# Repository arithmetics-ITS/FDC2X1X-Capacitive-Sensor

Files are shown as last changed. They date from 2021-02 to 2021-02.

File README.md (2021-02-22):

# Breakout Board: FDC2212 EMI-Resistant 28-Bit Capacitance-to-Digital Converter for Proximity and  Level Sensing Application
## Description

Capacitive sensing is a low-power, low-cost, high-resolution contactless sensing technique that can be applied to a variety of applications ranging from proximity detection and gesture recognition to remote liquid level sensing. The sensor in a capacitive sensing system is any metal or conductor, allowing for low cost and highly flexible system design. The main challenge limiting sensitivity in capacitive sensing applications is noise susceptibility of the sensors. With the FDC2x1x innovative EMI resistant
architecture, performance can be maintained even in presence of high-noise environments.

The FDC2x1x is a multi-channel family of noise-and EMI-resistant, high-resolution, high-speed capacitance-to-digital converters for  implementing capacitive sensing solutions. The devices employ an innovative narrow-band based architecture to offer high rejection of noise and interferers while providing high resolution at highspeed. The devices support a wide excitation frequency range, offering flexibility in system design. A wide frequency range is especially useful for reliable sensing of conductive liquids such as detergent, soap, and ink.

## Features

- Texas Instruments FDC2212
- CTS Model 625 - 40MHz ultra-low voltage clock oscillator
-  SiP3243 - Ultra Low Leakage Load Switch

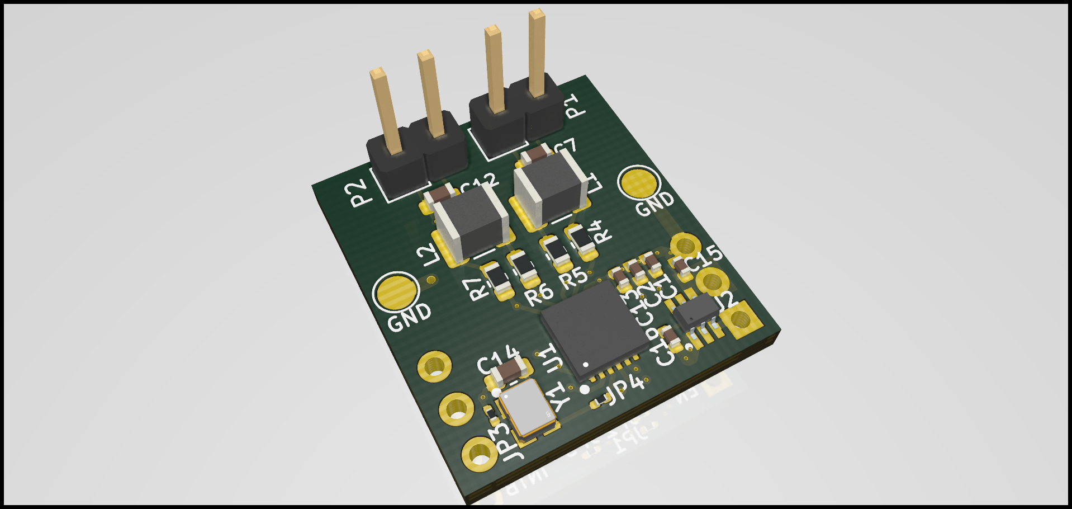
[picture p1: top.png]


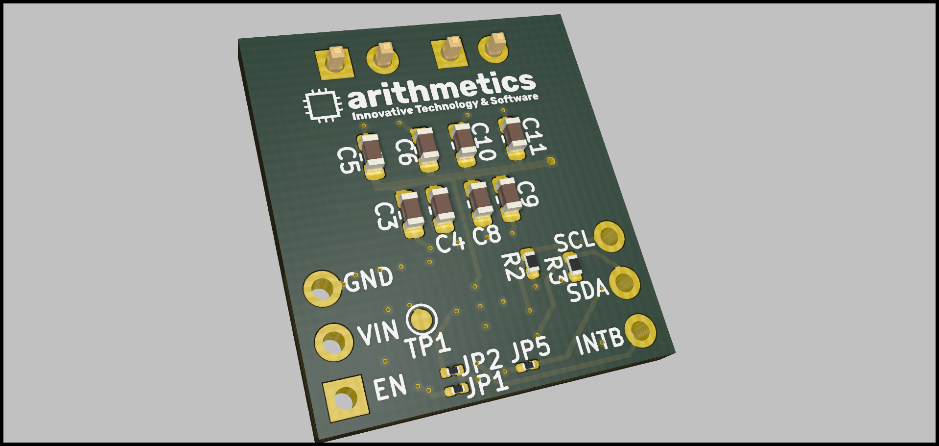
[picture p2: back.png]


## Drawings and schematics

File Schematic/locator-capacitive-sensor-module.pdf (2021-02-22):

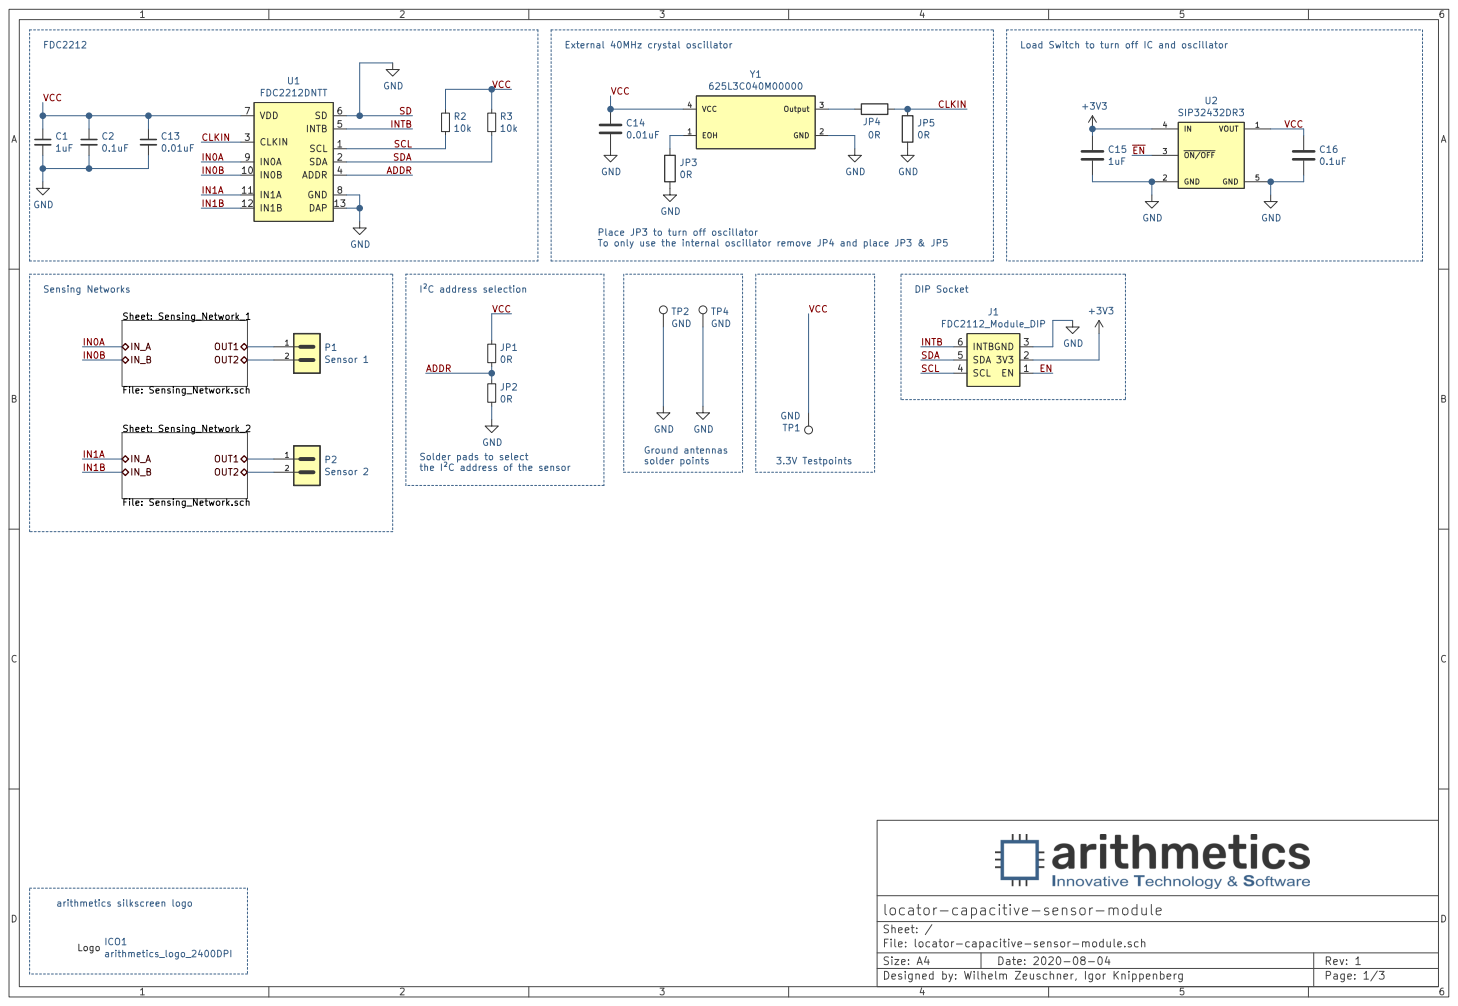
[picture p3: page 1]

locator-capacitive-sensor-module
File: locator-capacitive-sensor-module.sch Sheet: /

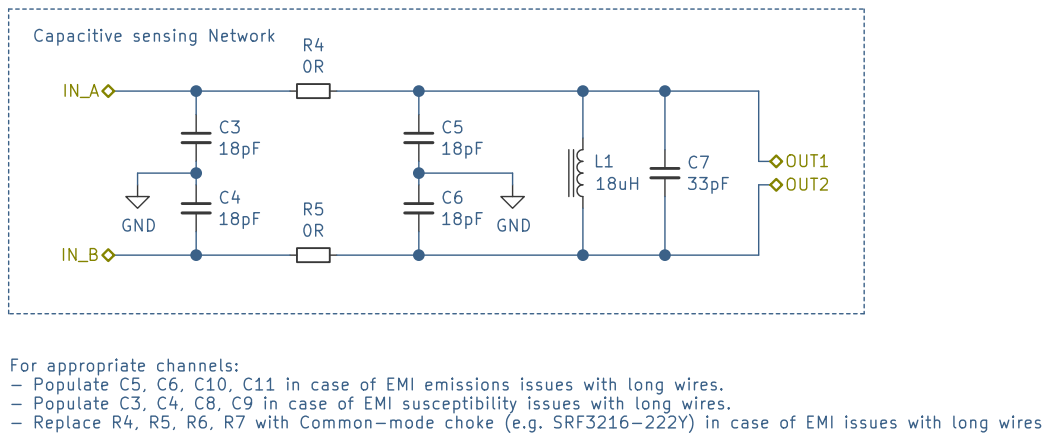
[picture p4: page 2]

For appropriate channels:
- Populate C5, C6, C10, C11 in case of EMI emissions issues with long wires.
- Populate C3, C4, C8, C9 in case of EMI susceptibility issues with long wires.
- Replace R4, R5, R6, R7 with Common-mode choke (e.g. SRF3216-222Y) in case of EMI issues with long wires

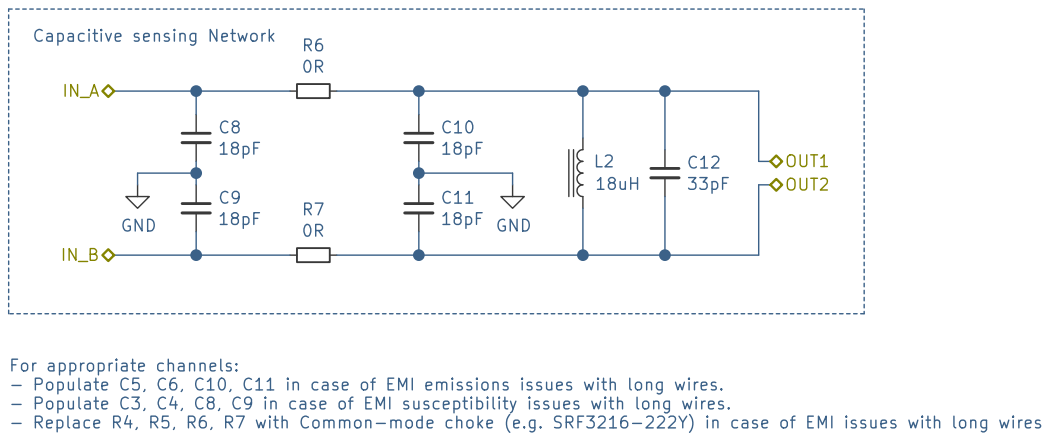
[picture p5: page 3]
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

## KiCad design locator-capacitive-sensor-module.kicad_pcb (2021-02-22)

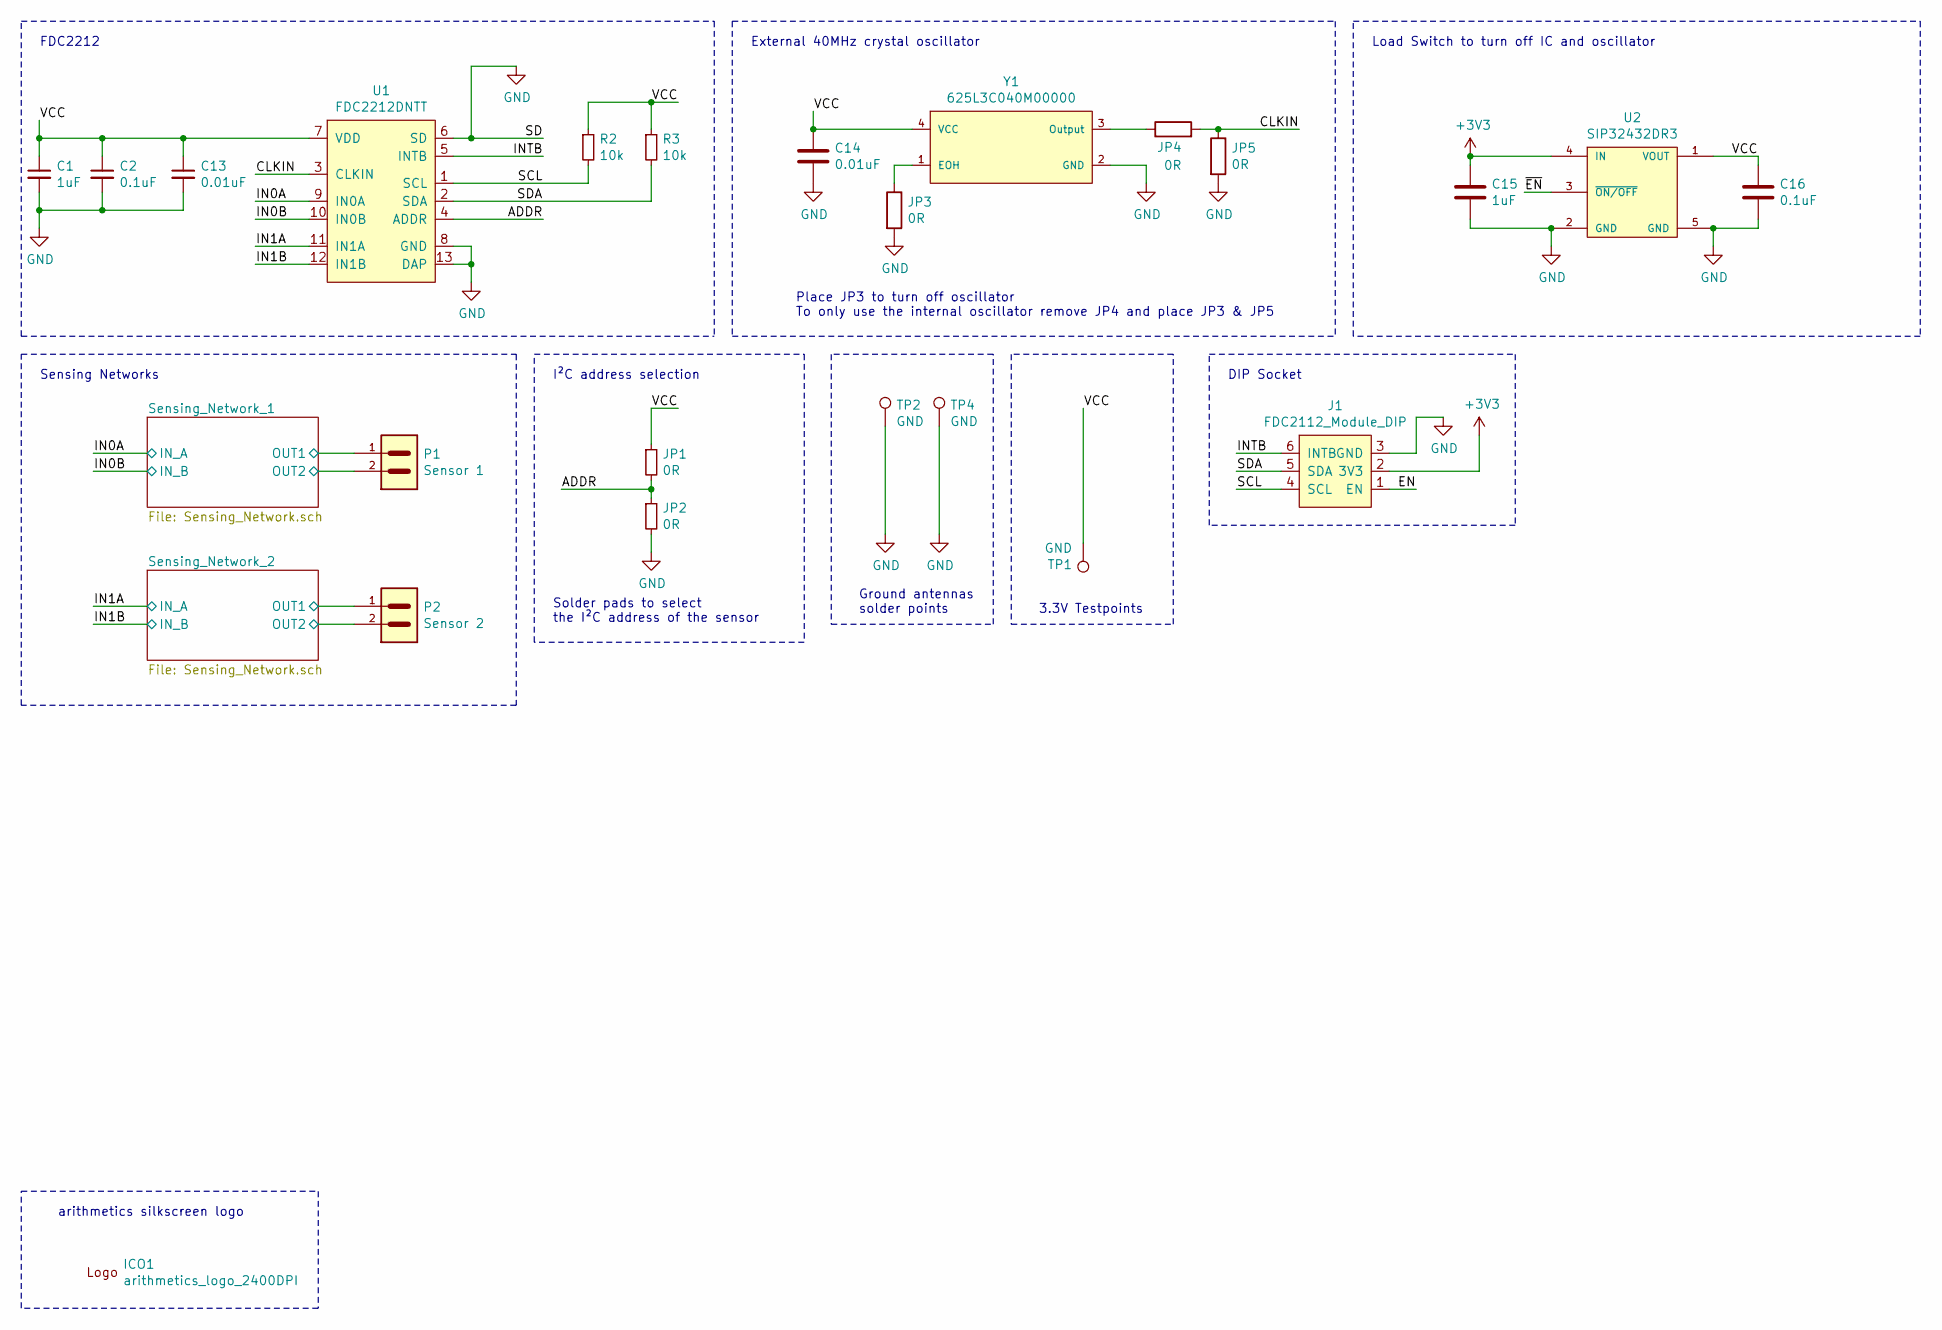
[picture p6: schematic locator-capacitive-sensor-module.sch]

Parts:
C1, C15: 1uF; C_0402_1005Metric; MPN C0402C105K8PACTU
C2, C16: 0.1uF; C_0402_1005Metric; MPN GCM155R71C104JA55D
C13: 0.01uF; C_0402_1005Metric; MPN C1005X7R1C103K050BA
C14: 0.01uF; C_0603_1608Metric; MPN C0603C103J3GECAUTO
ICO1: arithmetics_logo_2400DPI; logo_2400_DPI
J1: FDC2112_Module_DIP; Capacitive_Sensor_Module_Footprint_2
JP1, JP2, JP3, JP4, JP5: 0R; R_0201_0603Metric; MPN CR0201AJ/-000GLF
P1: Sensor 1; PinHeader_1x02_P2.54mm_Vertical
P2: Sensor 2; PinHeader_1x02_P2.54mm_Vertical
R2, R3: 10k; R_0402_1005Metric; MPN RC0402FR-0710KL
TP1: GND; TestPoint_Pad_D1.0mm
TP2, TP4: GND; TestPoint_Pad_D2.0mm
U1: FDC2212DNTT; FDC2112-Q1; MPN FDC2212DNTT
U2: SIP32432DR3; MPN SIP32432DR3-T1GE3
Y1: 625L3C040M00000; MPN 625L3C040M00000

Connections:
+3V3: C15.1, J1.2 (3V3), U2.4 (IN)
/ADDR: JP1.2, JP2.1, U1.4 (ADDR)
/CLKIN: JP4.2, JP5.1, U1.3 (CLKIN)
/IN0A: U1.9 (IN0A); also elsewhere on the board
/IN0B: U1.10 (IN0B); also elsewhere on the board
/IN1A: U1.11 (IN1A); also elsewhere on the board
/IN1B: U1.12 (IN1B); also elsewhere on the board
/INTB: J1.6 (INTB), U1.5 (INTB)
/SCL: J1.4 (SCL), R2.2, U1.1 (SCL)
/SDA: J1.5 (SDA), R3.2, U1.2 (SDA)
/Sensing_Network_1/OUT1: P1.1; also elsewhere on the board
/Sensing_Network_1/OUT2: P1.2; also elsewhere on the board
/Sensing_Network_2/OUT1: P2.1; also elsewhere on the board
/Sensing_Network_2/OUT2: P2.2; also elsewhere on the board
/VCC: C1.1, C2.1, C13.1, C14.1, C16.1, JP1.1, R2.1, R3.1, TP1.1, U1.7 (VDD), U2.1 (VOUT), Y1.4 (VCC)
GND: C1.2, C2.2, C13.2, C14.2, C15.2, C16.2, J1.3 (GND), JP2.2, JP3.2, JP5.2, TP2.1, TP4.1, U1.6 (SD), U1.8 (GND), U1.13 (DAP), U2.2 (GND), U2.5 (GND), Y1.2 (GND); also elsewhere on the board
unnamed: JP3.1, Y1.1 (EOH)
unnamed: JP4.1, Y1.3 (Output)

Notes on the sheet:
FDC2212
arithmetics silkscreen logo
External 40MHz crystal oscillator
Place JP3 to turn off oscillator To only use the internal oscillator remove JP4 and place JP3 & JP5
Load Switch to turn off IC and oscillator
DIP Socket
Ground antennas solder points
Solder pads to select the I²C address of the sensor
I²C address selection
Sensing Networks
3.3V Testpoints

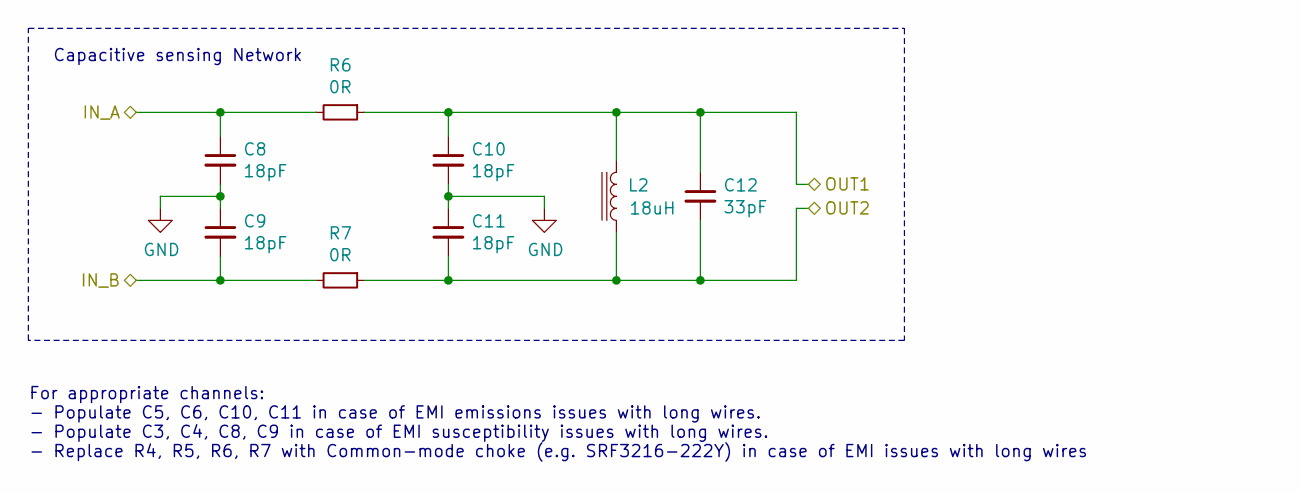
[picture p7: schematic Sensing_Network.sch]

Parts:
C3, C4, C5, C6: 18pF; C_0603_1608Metric; MPN C0603C180F5GAC7867
C7: 33pF; C_0603_1608Metric; MPN C0603C330F5GACTU
L1: 18uH; L_1210_3225Metric; MPN CMH322522-180KL
R4, R5: 0R; R_0603_1608Metric; MPN RC0603JR-070RL

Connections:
/IN0A: C3.1, R4.2; also elsewhere on the board
/IN0B: C4.2, R5.2; also elsewhere on the board
/Sensing_Network_1/OUT1: C5.1, C7.1, L1.2, R4.1; also elsewhere on the board
/Sensing_Network_1/OUT2: C6.2, C7.2, L1.1, R5.1; also elsewhere on the board
GND: C3.2, C4.1, C5.2, C6.1; also elsewhere on the board

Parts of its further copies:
C8, C9, C10, C11: 18pF; C_0603_1608Metric; MPN C0603C180F5GAC7867
C12: 33pF; C_0603_1608Metric; MPN C0603C330F5GACTU
L2: 18uH; L_1210_3225Metric; MPN CMH322522-180KL
R6, R7: 0R; R_0603_1608Metric; MPN RC0603JR-070RL

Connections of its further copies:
/IN1A: C8.1, R6.2; also elsewhere on the board
/IN1B: C9.2, R7.2; also elsewhere on the board
/Sensing_Network_2/OUT1: C10.1, C12.1, L2.2, R6.1; also elsewhere on the board
/Sensing_Network_2/OUT2: C11.2, C12.2, L2.1, R7.1; also elsewhere on the board
GND: C8.2, C9.1, C10.2, C11.1; also elsewhere on the board

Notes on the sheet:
Capacitive sensing Network
For appropriate channels: - Populate C5, C6, C10, C11 in case of EMI emissions issues with long wires. - Populate C3, C4, C8, C9 in case of EMI susceptibility issues with long wires. - Replace R4, R5, R6, R7 with Common-mode choke (e.g. SRF3216-222Y) in case of EMI issues with long wires

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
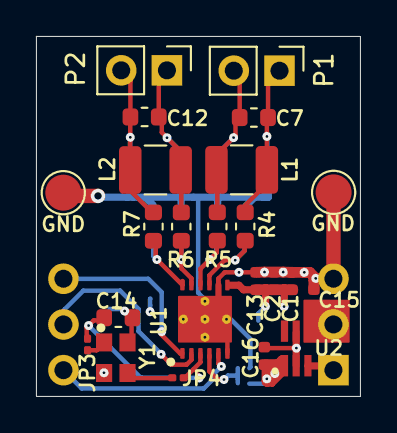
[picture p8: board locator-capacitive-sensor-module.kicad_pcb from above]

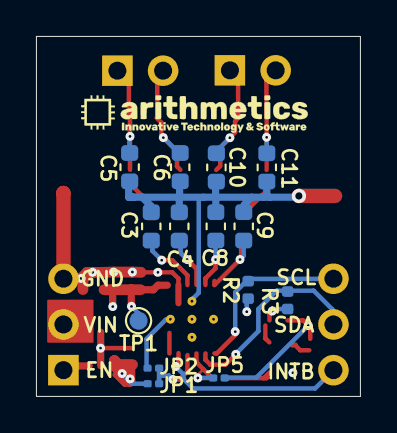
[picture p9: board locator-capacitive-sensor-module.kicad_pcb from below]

Board: 4 copper layers, 18.0 x 20.0 mm, 39 parts (15 on the bottom side), 19 nets.
